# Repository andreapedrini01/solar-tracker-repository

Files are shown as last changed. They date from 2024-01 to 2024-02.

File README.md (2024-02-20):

# Solar tracker


## Table of contents
- [About the project](#about-the-project)
- [Requirements](#requirements)
  - [Hardware](#hardware)
  - [Software](#software)
- [Installation](#installation)
- [Getting started](#getting-started)
- [Functionalities explanation](#functionalities-explanation)
- [Known Issues](#known-issues)
- [Team](#team)

## About the project
The idea of this project not only arises from the challenge of how to take advantage of the benefits and features of a microcontroller like the MSP432P401R, but also from how to provide a solution to a real-world problem.
For this reason, the implementation of a solar tracker was chosen. In this way, we could enhance the efficiency of solar panels by enabling active tracking of the sun's movement throughout the day.
Our goal for this solar tracker project is to implement it in the simplest way possible, leveraging the inherent functionality of the MSP432P401R and avoiding the use of other types of microcontrollers. All of this within a structure capable of providing support and stability for the photoresistors, solar panels, and transmitters that will enable the movement of the entire structure.

- [PowerPoint presentation](https://docs.google.com/presentation/d/1o80_3NKI8f1lPXFbKVqxCV8jqO51_DSNfxD5pUymfhE/edit?usp=sharing)
- Video demostration <...>

## Requirements
#### Hardware
The hardware required for this project is listed as follows:

- Texas Instruments MSP432P401R microcontroller
- 2 Gearboxes MG17-G100
- 2 Stepper motors NEMA 17HE15-1504S
- 4 Photoresistor GL5516
- 10 kΩ Current-limiting resistors
- Jumper wires
- 10 Solar panels 6V, 50mA
- Structure to assemble everything as a whole

#### Software
For this project, the following software is needed:
- Code Composer Studio as IDE
- Solidworks (For the design of the containing structure)

## Pin scheme
|Pin|Description|
|--|--|
|GND|xx|
|5V|xx|
|P1.6|STEP Pin Base stepper|
|P1.7|DIR Pin Base stepper|
|P2.5|DIR Pin Base stepper|
|P2.6|STEP Pin Top stepper|
|P5.0|Photoresistor (Red)|
|P5.1|Photoresistor (Green)|
|P5.2|Photoresistor (Black)|
|P5.4|Photoresistor (Blue)|

## Installation
Clone the repository
```
git clone https://github.com/andreapedrini01/solar-tracker-repository.git
```

## Getting started
1. Open the project in Code Composer Studio.
2. On the Arm Compiler options add the source directory:
   > *simplelink_msp432_sdk_3_40_01_02/*
3. On the Arm Linker options, add the following path:
   > *[...]/simplelink_msp432p4_sdk_3_40_01_02/source/ti/devices/msp432p4xx/driverlib/ccs/msp432p4xx_driverlib.lib*
4. Build and run the project.

## Functionalities explanation
Once the solar tracker structure is connected to power and the microcontroller is linked to the computer containing the project's code, we compile and launch the code using Code Composer Studio.

The following points denote the most important code sections that allow the visualization of data and configuration of the necessary components to enable the movement of the structure to make this structure an effective solar tracker.

#### Initialization of hardware and motors 
Given that the microcontroller we are using is an MSP432P401R and it is highly configurable, a proper initialization of its peripherals is important for optimal operation.
```c
void _hwInit()
{
    // Halting WDT and disabling master interrupts
    WDT_A_holdTimer();
    Interrupt_disableMaster();
    init_motors();
    _adcInit();
}
```
The function above is responsible for initializing the necessary hardware for the system's operation, such as the stepper motor, the ADC (Analog-to-Digital Converter), and any other required configurations.

```c
void init_motors() {
    //base motor
    init_baseStepper();

    //top motor
    init_topStepper();
}
```
The movement of the solar tracker is based on biaxial motion, so we initialize the base and top motors, which are responsible for horizontal and vertical movements, respectively.

We observe the initialization of the base motor. For the vertical movement, the motor is initialized in a similar manner.

```c
void init_baseStepper() {
    // Initialize the port and pin
    MAP_WDT_A_holdTimer();

    // Configure the pins as outputs
    MAP_GPIO_setAsOutputPin(GPIO_PORT_P1, BASE_STEP_PIN | BASE_DIR_PIN);

   // Set pins to initial low level
    MAP_GPIO_setOutputLowOnPin(GPIO_PORT_P1, BASE_STEP_PIN | BASE_DIR_PIN);
}
```

#### Initialization of ADC

```c
void _adcInit(){
        /* Configures Pin 6.0 and 4.4 as ADC input */
        GPIO_setAsPeripheralModuleFunctionInputPin(GPIO_PORT_P5, GPIO_PIN2, GPIO_TERTIARY_MODULE_FUNCTION);
        GPIO_setAsPeripheralModuleFunctionInputPin(GPIO_PORT_P5, GPIO_PIN1, GPIO_TERTIARY_MODULE_FUNCTION);
        GPIO_setAsPeripheralModuleFunctionInputPin(GPIO_PORT_P5, GPIO_PIN0, GPIO_TERTIARY_MODULE_FUNCTION);
        GPIO_setAsPeripheralModuleFunctionInputPin(GPIO_PORT_P5, GPIO_PIN4, GPIO_TERTIARY_MODULE_FUNCTION);

        /* Initializing ADC (ADCOSC/64/8) */
        ADC14_enableModule();
        ADC14_initModule(ADC_CLOCKSOURCE_ADCOSC, ADC_PREDIVIDER_64, ADC_DIVIDER_8, 0);

...

}

```
`adcInit()` is an extremely important function as it initializes the ADC (Analog-to-Digital Converter) and configures the pins 5.2, 5.1, 5.0 and 5.4 of the microcontroller as ADC inputs without which it would be impossible to directly read the values of the photoresistors in digital form. The photoresistors provide an analog output that varies depending on the intensity of the incident light, and this analog signal must be converted to digital so that the microcontroller can interpret it.

#### Read and Movement Functions
The functions responsible for controlling both motors to move or not are `readAndMove()`, `horMov()`, and `verMov()`. 

In reality, these three functions differ in few aspects (ignoring the obvious difference between `horMov()` and `verMov()`, which differ in the orientation of the displacement) since, in practical terms, they accomplish the same task. However, the existence and invocation of each one of them depend on what needs to be tested.

The utility of `readAndMove()` is that it first calculates the current position of both motors to eventually move them. Meanwhile, `horMov()` and `verMov()` allow reading the current position and moving the top motor only if the movement of the base motor has already finished.

For the sake of practicality, we will break down the operation of `horMov()` for explanation.

```c
void horMov() {
       int horizontalSteps = 0;
       int diff1 = 0;
       int diff1_1 = 0;

      /* Store ADC14 conversion results */
           resultsBuffer[0] = ADC14_getResult(ADC_MEM0);
           resultsBuffer[1] = ADC14_getResult(ADC_MEM1);
           resultsBuffer[2] = ADC14_getResult(ADC_MEM2);
           resultsBuffer[3] = ADC14_getResult(ADC_MEM3);
...
```
First, the values of the four light sensors are read and stored in the `resultsBuffer[]` array. These values represent the intensity of light received by each sensor. Subsequently, the average intensity of light is calculated from the sensor values. This average is used later to make decisions about the movement of the panel.

```c
...
       int avgIntensity = 0;
       int i=0;
       for (i = 0; i < NUM_SENSORS; i++) {
           avgIntensity += resultsBuffer[i];
       }
       avgIntensity /= NUM_SENSORS;
...
```
To detect changes in the intensity of incident light, the differences between the values of horizontally opposite sensors are calculated to determine if there has been a significant change in this intensity.
```c
...
if (avgIntensity > LIGHT_THRESHOLD) {
           diff1 = resultsBuffer[0] - resultsBuffer[1];
           diff1_1 = resultsBuffer[3] - resultsBuffer[2];
...
```
If a significant change in the intensity of light is detected, this change is mapped to motor steps. This involves converting the intensity difference into a specific number of steps that the motor must perform.
```c
...
if (abs(diff1) >= VALUE_CHANGE) {
    horizontalSteps = map(diff1, -16383, 16383, -10000, 10000);
} else if (abs(diff1_1) >= VALUE_CHANGE)
    horizontalSteps = map(diff1_1, -16383, 16383, -10000, 10000);
...
```
Limits are applied to the motor steps to ensure safe movement within the established range. Then, pulses are sent to the base motor to move the solar panel in the appropriate horizontal direction.
```c
...
           if (horizontalSteps != 0) {
              horizontalSteps = limitSteps(base_position,horizontalSteps);
              base_position += horizontalSteps;
              moveBase(horizontalSteps);
          }
       }
}
```
However, before concluding the breakdown of this function, we encounter the invocation of `moveBase()`, which indeed is responsible for the operation of the motor at the logical-mathematical level. The `moveBase()` function, along with other directly related functions, is found in the *StepperLib* library, where we can also find functions responsible for the top motor.

The function below (which is within the definition of the library) sends a single pulse to the control pin of the base motor. Each motor pulse produces a small angular movement. These pulses are essential for the motor to advance or reverse one step at a time. The duration of the pulse and the delay between pulses can be adjusted to control the speed and smoothness of the motor's movement.
```c
void stepBaseMotor() {
        MAP_GPIO_setOutputHighOnPin(GPIO_PORT_P1, BASE_STEP_PIN);
        __delay_cycles(5000); 
        MAP_GPIO_setOutputLowOnPin(GPIO_PORT_P1, BASE_STEP_PIN);
}
```
Finally, referring to `moveBase()`, it controls the direction of movement of the base motor and the number of steps it should take. Depending on the "steps" parameter, the motor will move forward or backward. The steps are generated using the `stepBaseMotor()` function in a for loop. This ensures that the base motor moves exactly the specified number of steps.

```c
void moveBase(int steps) {
    if (steps > 0) {
        // moveBaseForward
        MAP_GPIO_setOutputLowOnPin(GPIO_PORT_P1, BASE_DIR_PIN);
    } else {
        // moveBaseBackward
        steps = 0 - steps;
        MAP_GPIO_setOutputHighOnPin(GPIO_PORT_P1, BASE_DIR_PIN);
    }
    // Generate steps
    int i;
    for (i = 0; i < steps; i++) {
        stepBaseMotor();
        __delay_cycles(250); 
    }
}
```
Summarizing, these functions are essential for the operation of the stepper motors. They provide the precise control needed to move the solar panels in the correct direction and distance to maximize solar energy capture. Without proper control of the motor steps, solar tracking would not be possible.

## Known Issues
#### Jumper impedance
The issue with jumper impedance arises due to the use of jumper wires, which might introduce resistance and affect the accuracy of sensor readings or the performance of the motors. This impedance can lead to voltage drops and signal distortions, especially over long distances or in the presence of electromagnetic interference. To mitigate this issue, we could consider the following improvements:

- Use of Shielded Cables: Replace jumper wires with shielded cables to minimize interference from external sources.
- Shorter Wire Lengths: Keep the length of wires as short as possible to reduce resistance and signal degradation.

#### Multiple reading in one cycle
The issue of multiple readings in one cycle can occur when the code is not properly synchronized with the sampling rate of the ADC. This can lead to inaccurate readings or redundant calculations, affecting the overall performance of the solar tracker. To address this issue, we could implement the following improvements:

- Synchronization with ADC Conversion: Ensure that the code waits for the completion of each ADC conversion before initiating another reading. This can be achieved by using interrupts to synchronize the code with the ADC sampling rate.
- Error Handling: Implement error handling mechanisms to detect and handle cases where multiple readings occur unexpectedly, ensuring the reliability and robustness of the system.
  
## Team
| Members | Mail |
|--|--|
| Andrea Pedrini | andrea.pedrini@studenti.unitn.it |
| Irina Voloshina | irina.voloshina@studenti.unitn.it |
| Riccardo Stiz | riccardo.stiz@studenti.unitn.it |
| Francheska Paz Contreras Delgado | fp.contrerasdelgado@studenti.unitn.it |

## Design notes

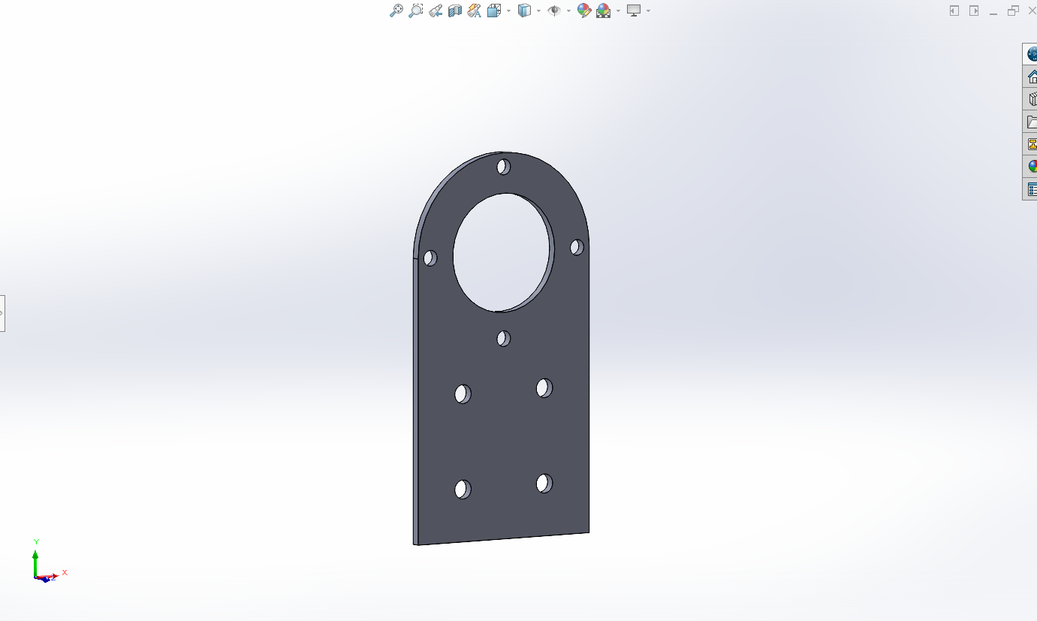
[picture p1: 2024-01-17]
SOLIDWORKS/BRACKET IMAGE.png

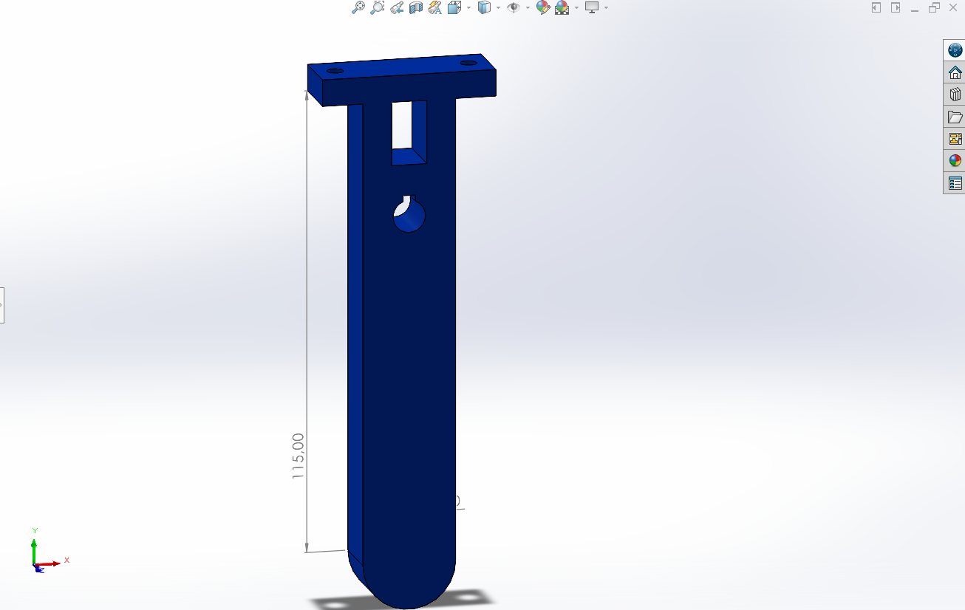
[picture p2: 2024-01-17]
SOLIDWORKS/ARM IMAGE.png

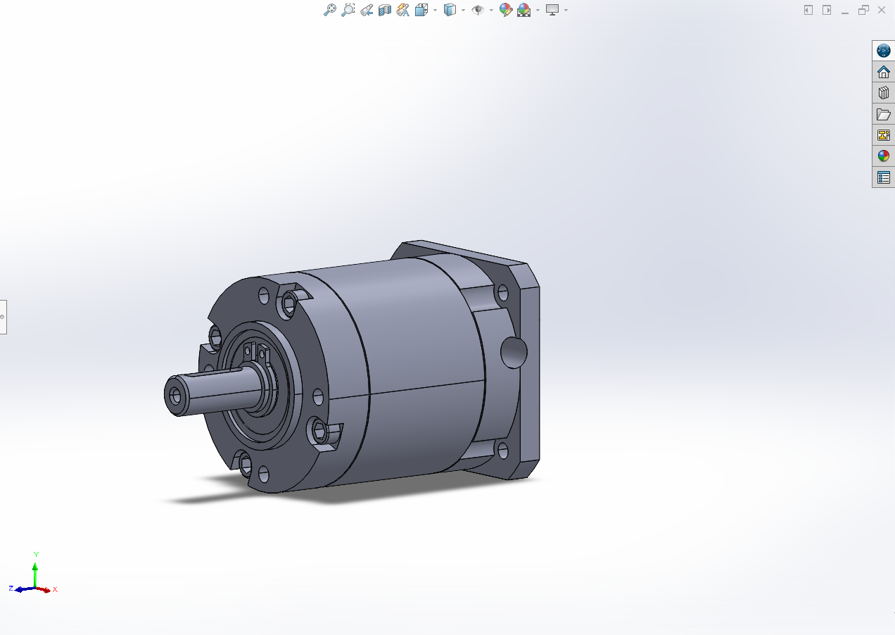
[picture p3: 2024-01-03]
SOLIDWORKS/GEARBOX IMAGE.png

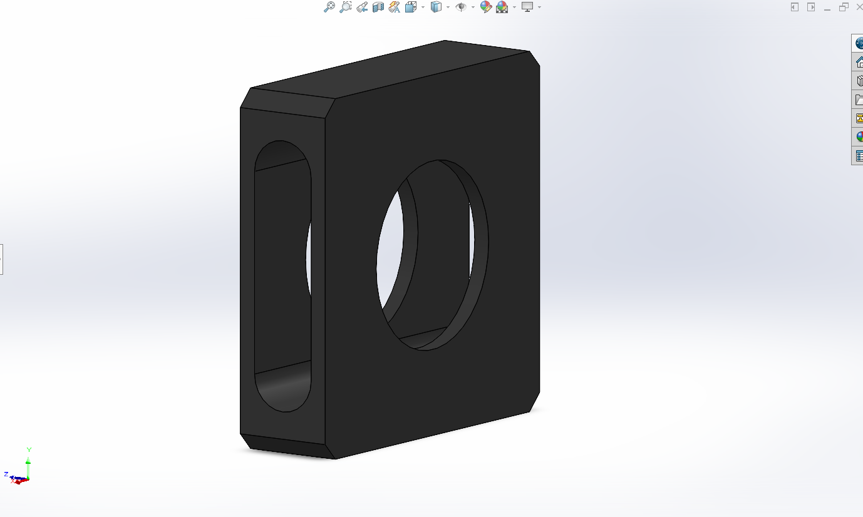
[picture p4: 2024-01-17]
SOLIDWORKS/LINK IMAGE.png

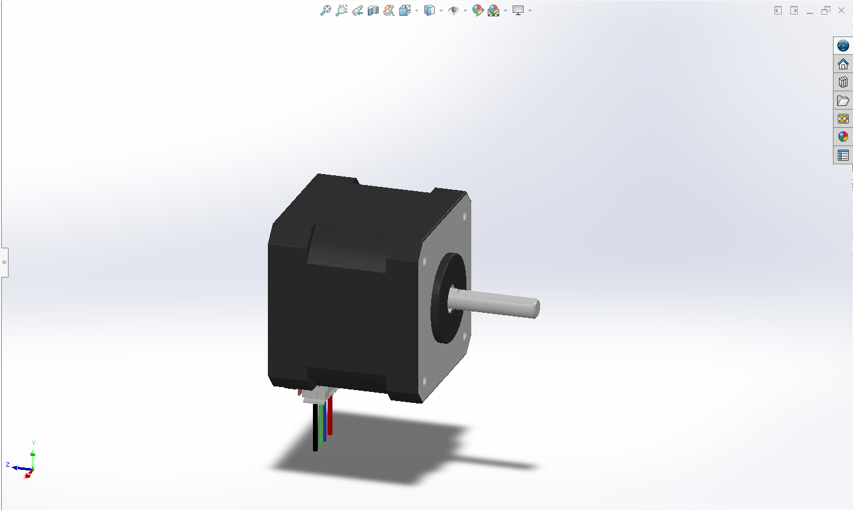
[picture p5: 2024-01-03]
SOLIDWORKS/17HE15-1504S IMAGE.png

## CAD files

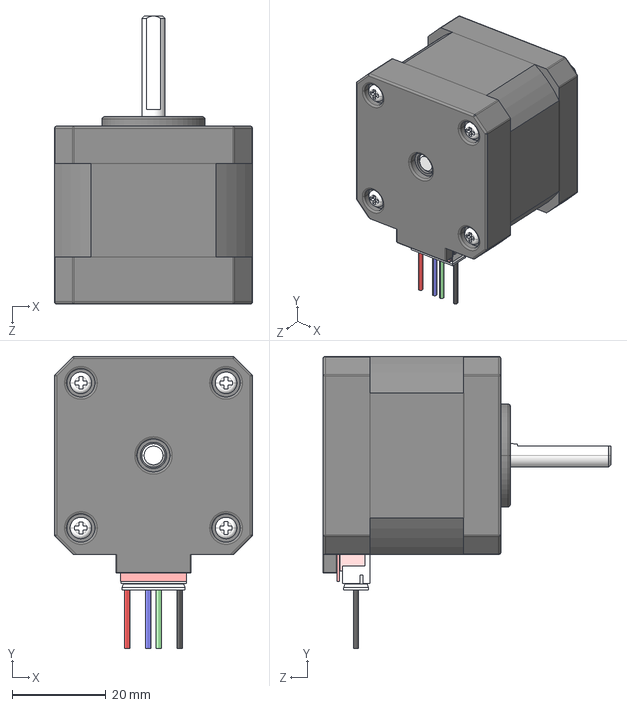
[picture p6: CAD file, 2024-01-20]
SOLIDWORKS/17HE15-1504S.STEP
42.3 x 62.4 x 61.5 mm

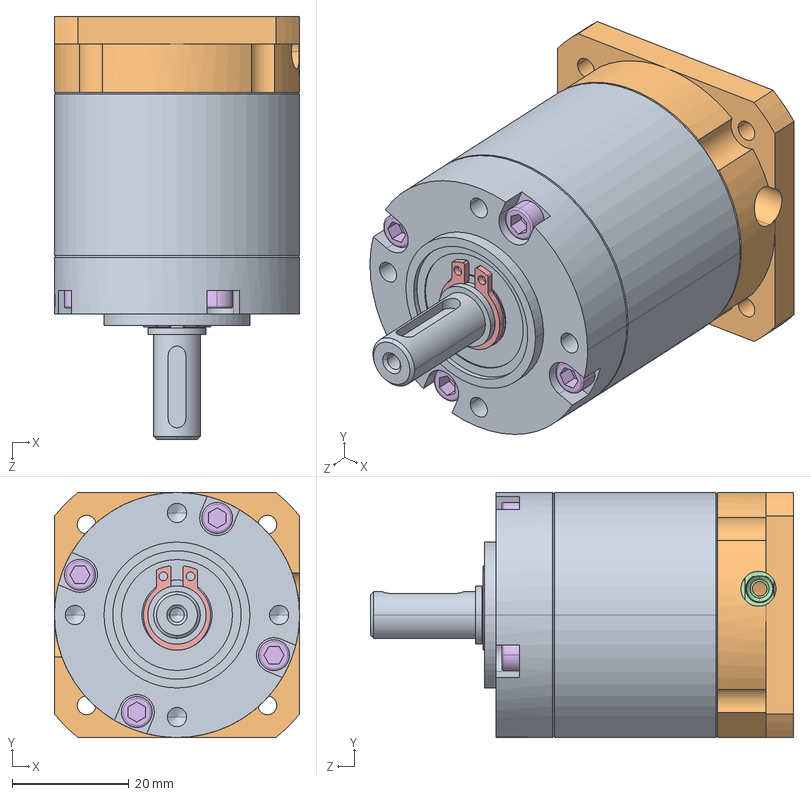
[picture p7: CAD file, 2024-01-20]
SOLIDWORKS/GEARBOX MG17-G100.STEP
42.0 x 42.0 x 72.5 mm
MG17 output-2
42GN Input flange
Input shaft
Φ10Circlip
M3 hexagon socket screw head x 8

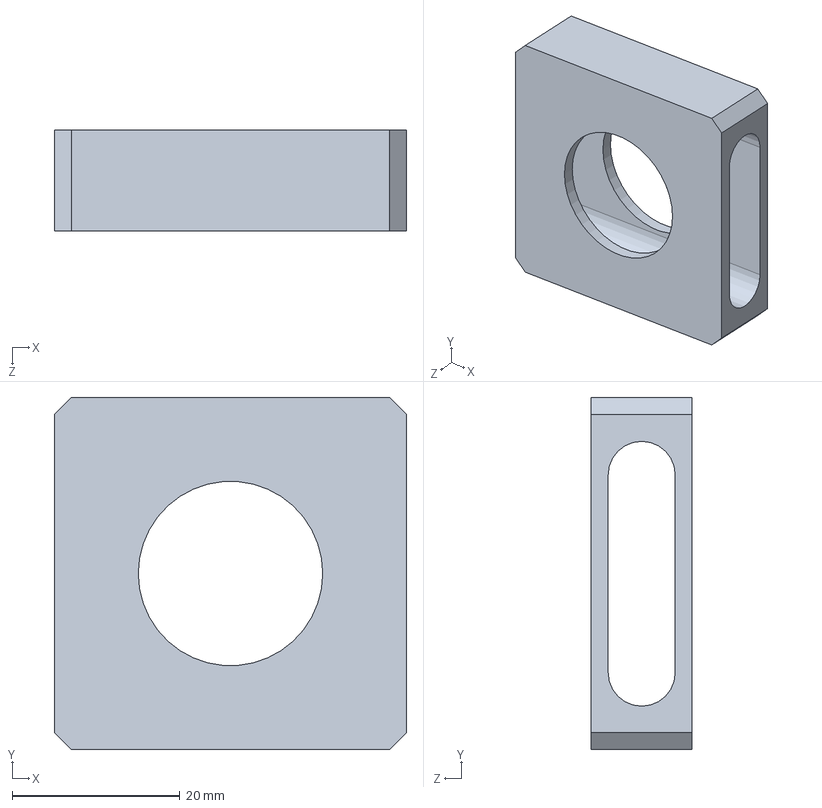
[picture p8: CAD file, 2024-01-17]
SOLIDWORKS/LINK.SLDPRT
42.0 x 42.0 x 12.0 mm

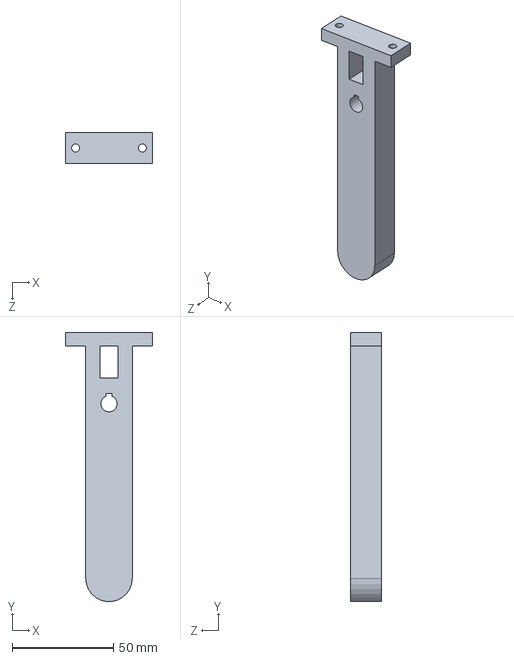
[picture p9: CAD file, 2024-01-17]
SOLIDWORKS/ARM.SLDPRT
43.0 x 133.0 x 15.5 mm

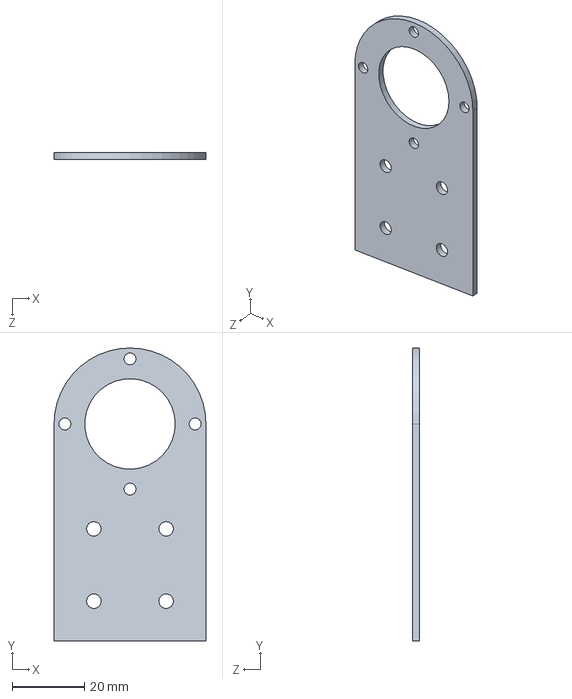
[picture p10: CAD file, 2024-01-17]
SOLIDWORKS/BRACKET.SLDPRT
42.0 x 81.0 x 2.00 mm

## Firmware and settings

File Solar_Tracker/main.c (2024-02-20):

#include "msp.h"
#include <ti/devices/msp432p4xx/inc/msp.h>
#include <ti/devices/msp432p4xx/driverlib/driverlib.h>
#include <ti/grlib/grlib.h>
#include <stdio.h>
#include <StepperLib/base_stepper.h>
#include <stepperLib/top_stepper.h>

#define NUM_SENSORS 4
#define VALUE_CHANGE 30
#define LIGHT_THRESHOLD 0 // Adjust this threshold as needed
#define MOVIMENTO 3000
#define MAX_MOVIMENTO 5000

static uint16_t resultsBuffer[NUM_SENSORS];

int boolFunction = 0;
int base_position = 0;
int top_position = 0;

void init_motors() {
    //base motor
    init_baseStepper();

    //top motor
    init_topStepper();
}

void _adcInit(){
    /* Configures Pin 6.0 and 4.4 as ADC input */
        GPIO_setAsPeripheralModuleFunctionInputPin(GPIO_PORT_P5, GPIO_PIN2, GPIO_TERTIARY_MODULE_FUNCTION);
        GPIO_setAsPeripheralModuleFunctionInputPin(GPIO_PORT_P5, GPIO_PIN1, GPIO_TERTIARY_MODULE_FUNCTION);
        GPIO_setAsPeripheralModuleFunctionInputPin(GPIO_PORT_P5, GPIO_PIN0, GPIO_TERTIARY_MODULE_FUNCTION);
        GPIO_setAsPeripheralModuleFunctionInputPin(GPIO_PORT_P5, GPIO_PIN4, GPIO_TERTIARY_MODULE_FUNCTION);

        /* Initializing ADC (ADCOSC/64/8) */
        ADC14_enableModule();
        ADC14_initModule(ADC_CLOCKSOURCE_ADCOSC, ADC_PREDIVIDER_64, ADC_DIVIDER_8, 0);

        /* Configuring ADC Memory (ADC_MEM0 - ADC_MEM1 (A15, A9)  with repeat)
             * with internal 2.5v reference */
        ADC14_configureMultiSequenceMode(ADC_MEM0, ADC_MEM3, true);
        ADC14_configureConversionMemory(ADC_MEM0,
                ADC_VREFPOS_AVCC_VREFNEG_VSS,
                ADC_INPUT_A3, ADC_NONDIFFERENTIAL_INPUTS);

        ADC14_configureConversionMemory(ADC_MEM1,
                ADC_VREFPOS_AVCC_VREFNEG_VSS,
                ADC_INPUT_A4, ADC_NONDIFFERENTIAL_INPUTS);

        ADC14_configureConversionMemory(ADC_MEM2,
                        ADC_VREFPOS_AVCC_VREFNEG_VSS,
                        ADC_INPUT_A5, ADC_NONDIFFERENTIAL_INPUTS);

        ADC14_configureConversionMemory(ADC_MEM3,
                                ADC_VREFPOS_AVCC_VREFNEG_VSS,
                                ADC_INPUT_A1, ADC_NONDIFFERENTIAL_INPUTS);

        /* Setting up the sample timer to automatically step through the sequence
         * convert.
         */
        ADC14_enableSampleTimer(ADC_AUTOMATIC_ITERATION);

        /* Triggering the start of the sample */
        ADC14_enableConversion();
        ADC14_toggleConversionTrigger();
}

void _hwInit()
{
    // Halting WDT and disabling master interrupts
    WDT_A_holdTimer();
    Interrupt_disableMaster();

    //_graphicsInit();
    init_motors();
    _adcInit();
}

int map(int x, int in_min, int in_max, int out_min, int out_max)    //function useful in photoresistor algorithm
{
    long int top_part = (x - in_min) * (out_max - out_min);
    int bottom_part = in_max - in_min;
    return  (top_part / bottom_part) + out_min;
}

int limitSteps(int counter, int movement) {
    int steps = movement;
    // Upper limit check
    if (counter+movement > MAX_MOVIMENTO) {
        steps = movement - MAX_MOVIMENTO - MAX_MOVIMENTO;
    }
    // Lower limit check
    if (counter+movement < 0-MAX_MOVIMENTO) {
        steps = movement + MAX_MOVIMENTO + MAX_MOVIMENTO;
    }
    return steps;
}

void readAndMove() {

   int horizontalSteps = 0;
   int verticalSteps = 0;
   int diff1 = 0;
   int diff1_1 = 0;
   int diff2 = 0;
   int diff2_2 = 0;
   int i=0;

  /* Store ADC14 conversion results */
       resultsBuffer[0] = ADC14_getResult(ADC_MEM0);
       resultsBuffer[1] = ADC14_getResult(ADC_MEM1);
       resultsBuffer[2] = ADC14_getResult(ADC_MEM2);
       resultsBuffer[3] = ADC14_getResult(ADC_MEM3);

   int avgIntensity = 0;

   for (i = 0; i < NUM_SENSORS; i++) {
       avgIntensity += resultsBuffer[i];
   }
   avgIntensity /= NUM_SENSORS;

   if (avgIntensity > LIGHT_THRESHOLD) {
       diff1 = resultsBuffer[0] - resultsBuffer[1];
       diff1_1 = resultsBuffer[3] - resultsBuffer[2];
       /* See if there's an actual change in the value */
       if (abs(diff1) >= VALUE_CHANGE) {
           horizontalSteps = map(diff1, -16383, 16383, -10000, 10000);
       } else if (abs(diff1_1) >= VALUE_CHANGE) {
           horizontalSteps = map(diff1_1, -16383, 16383, -10000, 10000);
       }

       diff2 = resultsBuffer[0] - resultsBuffer[3];
       diff2_2 = resultsBuffer[1] - resultsBuffer[2];
       /* See if there's an actual change in the value */
       if (abs(diff2) >= VALUE_CHANGE)
           verticalSteps = map(diff2, -16383, 16383, -10000, 10000);
       else if (abs(diff2_2) >= VALUE_CHANGE)
           verticalSteps = map(diff2_2, -16383, 16383, -10000, 10000);
       // control if the motion has to be clockwise or anti-clockwise and send the impulses
       if (horizontalSteps != 0) {
          horizontalSteps = limitSteps(base_position,horizontalSteps);
          base_position += horizontalSteps;
          moveBase(horizontalSteps);
      }

       if (verticalSteps != 0) {
           verticalSteps = limitSteps(top_position, verticalSteps);
           top_position += verticalSteps;
           moveTop(verticalSteps);
       }
   }
   __delay_cycles(100);
}

void horMov() {
    int horizontalSteps = 0;
       int diff1 = 0;

      /* Store ADC14 conversion results */
           resultsBuffer[0] = ADC14_getResult(ADC_MEM0);
           resultsBuffer[1] = ADC14_getResult(ADC_MEM1);
           resultsBuffer[2] = ADC14_getResult(ADC_MEM2);
           resultsBuffer[3] = ADC14_getResult(ADC_MEM3);

       int avgIntensity = 0;
       int i=0;
       for (i = 0; i < NUM_SENSORS; i++) {
           avgIntensity += resultsBuffer[i];
       }
       avgIntensity /= NUM_SENSORS;

       if (avgIntensity > LIGHT_THRESHOLD) {
           diff1 = (resultsBuffer[1] + resultsBuffer[2])/2 - (resultsBuffer[0] + resultsBuffer[3])/2;

           /* See if there's an actual change in the value */
           if (abs(diff1) >= VALUE_CHANGE)
                      horizontalSteps = map(diff1, -16383, 16383, -10000, 10000);

           // control if the motion has to be clockwise or anti-clockwise and send the impulses
           if (horizontalSteps != 0) {
              horizontalSteps = limitSteps(base_position,horizontalSteps);
              base_position += horizontalSteps;
              moveBase(horizontalSteps);
          }
       }
}

void verMov() {
   int verticalSteps = 0;
   int diff2 = 0;

      /* Store ADC14 conversion results */
           resultsBuffer[0] = ADC14_getResult(ADC_MEM0);
           resultsBuffer[1] = ADC14_getResult(ADC_MEM1);
           resultsBuffer[2] = ADC14_getResult(ADC_MEM2);
           resultsBuffer[3] = ADC14_getResult(ADC_MEM3);

       int avgIntensity = 0;
       int i=0;
       for (i = 0; i < NUM_SENSORS; i++) {
           avgIntensity += resultsBuffer[i];
       }
       avgIntensity /= NUM_SENSORS;

       diff2 = (resultsBuffer[0] + resultsBuffer[1])/2 - (resultsBuffer[3] + resultsBuffer[2])/2;
       /* See if there's an actual change in the value */
       if (abs(diff2) >= VALUE_CHANGE)
                  verticalSteps = map(diff2, -16383, 16383, -10000, 10000);

       if (verticalSteps != 0) {
          verticalSteps = limitSteps(top_position, verticalSteps);
          top_position += verticalSteps;
          moveTop(verticalSteps);
       }
}

/*
 * Main function
 */
void main(void) {

    _hwInit();

    /*while(1) {
            moveTop(1);
        }*/

    if (boolFunction == 1) {
        while(1){
                // ADC_MEM1 conversion completed
                if(!ADC_INT1)
                   continue;

                readAndMove();

           }
    } else {
        int fullMovementCompleted = 1;
        while(1){
                // ADC_MEM1 conversion completed
                if(!ADC_INT1)
                   continue;

                if (fullMovementCompleted == 1) {
                    // move horizontal
                    horMov();
                    fullMovementCompleted = 0;
                } else {
                    //move vertical
                    verMov();
                    fullMovementCompleted = 1;
                }

           }
    }
}

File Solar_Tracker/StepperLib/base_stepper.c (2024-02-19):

#include <StepperLib/base_stepper.h>
#include <ti/devices/msp432p4xx/driverlib/driverlib.h>
#include "msp.h"

void init_baseStepper() {
    // Inizializza la port e i pin
    MAP_WDT_A_holdTimer();

    // Configura i pin come output
    MAP_GPIO_setAsOutputPin(GPIO_PORT_P1, BASE_STEP_PIN | BASE_DIR_PIN);

    // Imposta i pin a livello basso iniziale
    MAP_GPIO_setOutputLowOnPin(GPIO_PORT_P1, BASE_STEP_PIN | BASE_DIR_PIN);
}

void stepBaseMotor() {
    // Invia un impulso STEP
        MAP_GPIO_setOutputHighOnPin(GPIO_PORT_P1, BASE_STEP_PIN);
        __delay_cycles(5000); //Aggiungi un piccolo ritardo
        MAP_GPIO_setOutputLowOnPin(GPIO_PORT_P1, BASE_STEP_PIN);
}

void moveBase(int steps) {
    if (steps > 0) {
        // moveBaseForward
        MAP_GPIO_setOutputLowOnPin(GPIO_PORT_P1, BASE_DIR_PIN);
    } else {
        // moveBaseBackward
        steps = 0 - steps;
        MAP_GPIO_setOutputHighOnPin(GPIO_PORT_P1, BASE_DIR_PIN);
    }
    // Genera i passi
    int i;
    for (i = 0; i < steps; i++) {
        stepBaseMotor();
        __delay_cycles(250); // Aggiungi un ritardo tra i passi
    }
}

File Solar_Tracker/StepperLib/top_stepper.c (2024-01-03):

#include <StepperLib/top_stepper.h>
#include <ti/devices/msp432p4xx/driverlib/driverlib.h>
#include "msp.h"

void init_topStepper() {
    // Inizializza la port e i pin
    MAP_WDT_A_holdTimer();

    // Configura i pin come output
    MAP_GPIO_setAsOutputPin(GPIO_PORT_P2, TOP_STEP_PIN | TOP_DIR_PIN);

    // Imposta i pin a livello basso iniziale
    MAP_GPIO_setOutputLowOnPin(GPIO_PORT_P2, TOP_STEP_PIN | TOP_DIR_PIN);
}

void stepTopMotor() {
    // Invia un impulso STEP
        MAP_GPIO_setOutputHighOnPin(GPIO_PORT_P2, TOP_STEP_PIN);
        __delay_cycles(5000); // Aggiungi un piccolo ritardo
        MAP_GPIO_setOutputLowOnPin(GPIO_PORT_P2, TOP_STEP_PIN);
}

void moveTop(int steps) {
    if (steps > 0) {
        // moveTopForward
        MAP_GPIO_setOutputLowOnPin(GPIO_PORT_P2, TOP_DIR_PIN);
    } else {
        // moveTopBackward
        steps = 0 - steps;
        MAP_GPIO_setOutputHighOnPin(GPIO_PORT_P2, TOP_DIR_PIN);
    }
    // Genera i passi
    int i;
    for (i = 0; i < steps; i++) {
        stepTopMotor();
        __delay_cycles(250); // Aggiungi un ritardo tra i passi
    }
}

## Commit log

2023-11-30 top stepper library
2023-12-11 Defined sample MAX_STEPS (adjust if necessary)
2023-12-11 Added flip for negative values
    [main.c]
2023-12-11 Fixed sign change for steps
    [main.c]
2023-12-18 Enable pin removed
2023-12-18 Adjusted algorithm for motors movement using photoresistor readings
2024-01-20 let's see if this works
    [17HE15-1504S.STEP, GEARBOX MG17-G100.STEP]
2024-01-20 Scale down the readings to avoid overflow
    [main.c]
2024-01-29 Added check for two pairs of resistors
